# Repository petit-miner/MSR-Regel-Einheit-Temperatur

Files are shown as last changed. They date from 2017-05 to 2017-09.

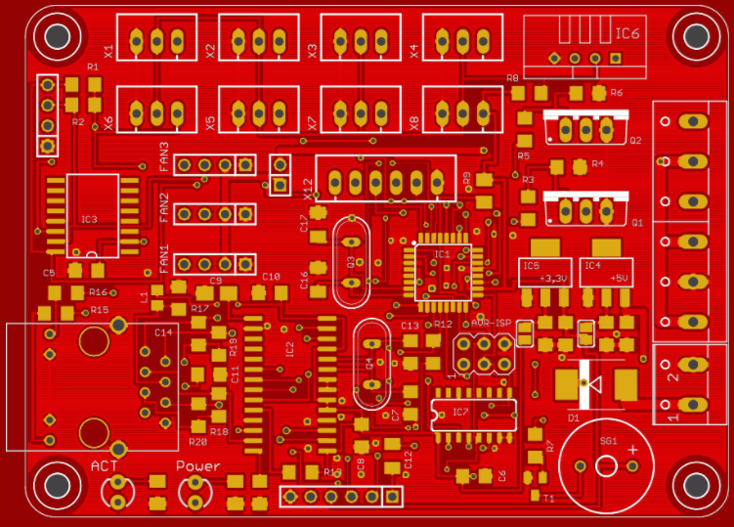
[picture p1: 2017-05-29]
Hardware/Bilder-Platine/Top.png

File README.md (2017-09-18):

# MSR-Regel-Einheit-Temperatur
Dieses Projekt entstand in der Technik / µC AG des CRBK. Die Aufgabe war es die Temperatur eines Schaltschrankes zu überwachen und ggf. mit einem Lüfter zu kühlen. <br>
Diese Platine bietet die Möglichkeit die gemessen Temperaturen auf einer micro SD Karte zu loggen und auch per Ethernet entweder als Webserver oder als Client die gemessenen Daten bereitzustellen.<br> Die RTC sorgt beim Loggen für eine ständig korrekte Zeit.<br>
Es können bis zu 8 Onewire Sensoren, 3 PC-Lüfter und 2 normale Lüfter an die Platine angeschlossen werden.
<br>
<br>
Die Gerber Dateien und der Schaltplan wurden unter der Open Source Hardware Lizenz veröffentlicht und dürfen für den nicht kommerziellen Zweck gerne weiter verwendet werden.
<br>
<br>
Dieses Projekt wurde von Marcel Thürmer, Justin Wellenberg, Julian Prochowicz und Till Flesch entwickelt.

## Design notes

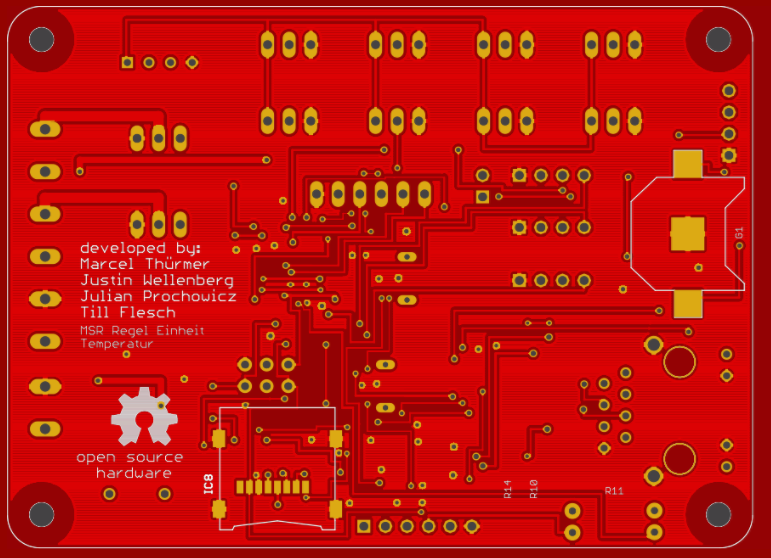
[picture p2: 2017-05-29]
Hardware/Bilder-Platine/Bottom.png

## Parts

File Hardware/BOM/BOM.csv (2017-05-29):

Part | Value | Device | Package | Description | PROD_ID | VALUE
C1 | 100nF | C-EUC1206 | C1206 | CAPACITOR, European symbol
C2 | 100nF | C-EUC1206 | C1206 | CAPACITOR, European symbol
C3 | 100nF | C-EUC1206 | C1206 | CAPACITOR, European symbol
C4 | 100nF | C-EUC1206 | C1206 | CAPACITOR, European symbol
C5 | 100nF | C-EUC1206 | C1206 | CAPACITOR, European symbol
C6 | 100nF | C-EUC1206 | C1206 | CAPACITOR, European symbol
C7 | 20pF | C-EUC1206 | C1206 | CAPACITOR, European symbol
C8 | 100nF | C-EUC1206 | C1206 | CAPACITOR, European symbol
C9 | 10µF | CPOL-EUA/3216-18W | A/3216-18W | POLARIZED CAPACITOR, European symbol
C10 | 100nF | C-EUC1206 | C1206 | CAPACITOR, European symbol
C11 | 100nF | C-EUC1206 | C1206 | CAPACITOR, European symbol
C12 | 100nF | C-EUC1206K | C1206K | CAPACITOR, European symbol
C13 | 20pF | C-EUC1206 | C1206 | CAPACITOR, European symbol
C14 | 100nF | C-EUC1206 | C1206 | CAPACITOR, European symbol
C16 | 22pF | C-EUC1206K | C1206K | CAPACITOR, European symbol
C17 | 22pF | C-EUC1206K | C1206K | CAPACITOR, European symbol
D1 | FS3J | DIODE-SMC | SMC | DIODE
D2 | LED | LED3MM | LED3MM | LEDs
D3 | LED | LED3MM | LED3MM | LEDs
G1 | RTC-battery | CR1220SMT | CR1220-SMD | CR1216/CR1220/CR1225 12mm 3V lithium coin cell
IC1 | ATMEGA328P_TQFP | ATMEGA328P_TQFP | TQFP32-08 | Popular 328P in QFP
IC2 | ENC28J60-SO | ENC28J60-SO | SO28W | Microchip 10Mbit Eth. contoller with SPI interface
IC3 | RTC | DS3231SOIC-16W | SOIC-16W
IC4 | Linearregler | LM1117 | SOT223
IC5 | Linearregler | LM1117 | SOT223 |  | IC-09069 | ATMEGA328P_TQFP
IC6 | TEMP-HUM-SENSOR-DHT22 | TEMP-HUM-SENSOR-DHT22 | TEMP-HUM-SENSOR-DHT22 | DHT22 - digital humidity & temperature sensor
IC7 | HEX_CONVERTER | HEX_CONVERTER | SO016 | 74HC4050 Hex Buffer Level Shifter SMD SO016
IC8 | TRANSFLASH-LOCK | TRANSFLASH-LOCK | TRANSFLASH-LOCK-SOCK | TransFlash TF Micro SD Card Socket Adapter
ISP1 | 10µH | L-EUL0805 | L0805 | INDUCTOR, European symbol
L1 | IRF512 | IRF512 | TO220BV | N-CHANNEL MOS FET
Q1 | IRF512 | IRF512 | TO220BV | N-CHANNEL MOS FET
Q2 | 16Mhz | XTAL/S | QS | CRYSTAL
Q3 | 25Mhz | XTAL/S | QS | CRYSTAL
Q4 | 10k | R-EU_R1206 | R1206 | RESISTOR, European symbol
R1 | 10k | R-EU_R1206 | R1206 | RESISTOR, European symbol
R2 | 270 | R-EU_R1206 | R1206 | RESISTOR, European symbol
R3 | 10k | R-EU_R1206 | R1206 | RESISTOR, European symbol
R4 | 270 | R-EU_R1206 | R1206 | RESISTOR, European symbol
R5 | 10k | R-EU_R1206 | R1206 | RESISTOR, European symbol
R6 | 1k | R-EU_R1206 | R1206 | RESISTOR, European symbol
R7 | 4,7k | R-EU_R1206 | R1206 | RESISTOR, European symbol
R8 | 10k | R-EU_M1206 | M1206 | RESISTOR, European symbol
R9 | 150 | R-EU_M1206 | M1206 | RESISTOR, European symbol
R10 | 150 | R-EU_M1206 | M1206 | RESISTOR, European symbol
R11 | 4,7K | R-EU_R1206 | R1206 | RESISTOR, European symbol
R12 | 4,7K | R-EU_R1206 | R1206 | RESISTOR, European symbol
R13 | 2.7K | R-EU_R1206 | R1206 | RESISTOR, European symbol
R14 | 1k | R-EU_R1206 | R1206 | RESISTOR, European symbol
R15 | 1k | R-EU_R1206 | R1206 | RESISTOR, European symbol
R16 | 50 | R-EU_R1206 | R1206 | RESISTOR, European symbol
R17 | 50 | R-EU_R1206 | R1206 | RESISTOR, European symbol
R18 | 50 | R-EU_R1206 | R1206 | RESISTOR, European symbol
R19 | 50 | R-EU_R1206 | R1206 | RESISTOR, European symbol
R20 | BUZZER | BUZZER | BUZZER-12MM-NS | Buzzer 12mm
SG1 | Transistor | BC817-16-NPN-SOT23-BEC | SOT23-BEC | NPN Transistror
T1 | HR911105A | HR911105A | RJ45
U$1 | JST-XH-03-PIN-LONG-PAD | JST-XH-03-PIN-LONG-PAD | JST-XH-03-PACKAGE-LONG-PAD | JST XH Connector 2 Pin
X1 | JST-XH-03-PIN-LONG-PAD | JST-XH-03-PIN-LONG-PAD | JST-XH-03-PACKAGE-LONG-PAD | JST XH Connector 2 Pin
X2 | JST-XH-03-PIN-LONG-PAD | JST-XH-03-PIN-LONG-PAD | JST-XH-03-PACKAGE-LONG-PAD | JST XH Connector 2 Pin
X3 | JST-XH-03-PIN-LONG-PAD | JST-XH-03-PIN-LONG-PAD | JST-XH-03-PACKAGE-LONG-PAD | JST XH Connector 2 Pin
X4 | JST-XH-03-PIN-LONG-PAD | JST-XH-03-PIN-LONG-PAD | JST-XH-03-PACKAGE-LONG-PAD | JST XH Connector 2 Pin
X5 | JST-XH-03-PIN-LONG-PAD | JST-XH-03-PIN-LONG-PAD | JST-XH-03-PACKAGE-LONG-PAD | JST XH Connector 2 Pin
X6 | JST-XH-03-PIN-LONG-PAD | JST-XH-03-PIN-LONG-PAD | JST-XH-03-PACKAGE-LONG-PAD | JST XH Connector 2 Pin
X7 | JST-XH-03-PIN-LONG-PAD | JST-XH-03-PIN-LONG-PAD | JST-XH-03-PACKAGE-LONG-PAD | JST XH Connector 2 Pin
X8 | Wago Schraubklemme | W237-102 | W237-102 | WAGO SCREW CLAMP
X9 | Wago Schraubklemme | W237-6 | W237-6 | WAGO SCREW CLAMP
X10 | JST-XH-06-PIN-LONG-PAD | JST-XH-06-PIN-LONG-PAD | JST-XH-06-PACKAGE-LONG-PAD | JST XH Connector 2 Pin
X12

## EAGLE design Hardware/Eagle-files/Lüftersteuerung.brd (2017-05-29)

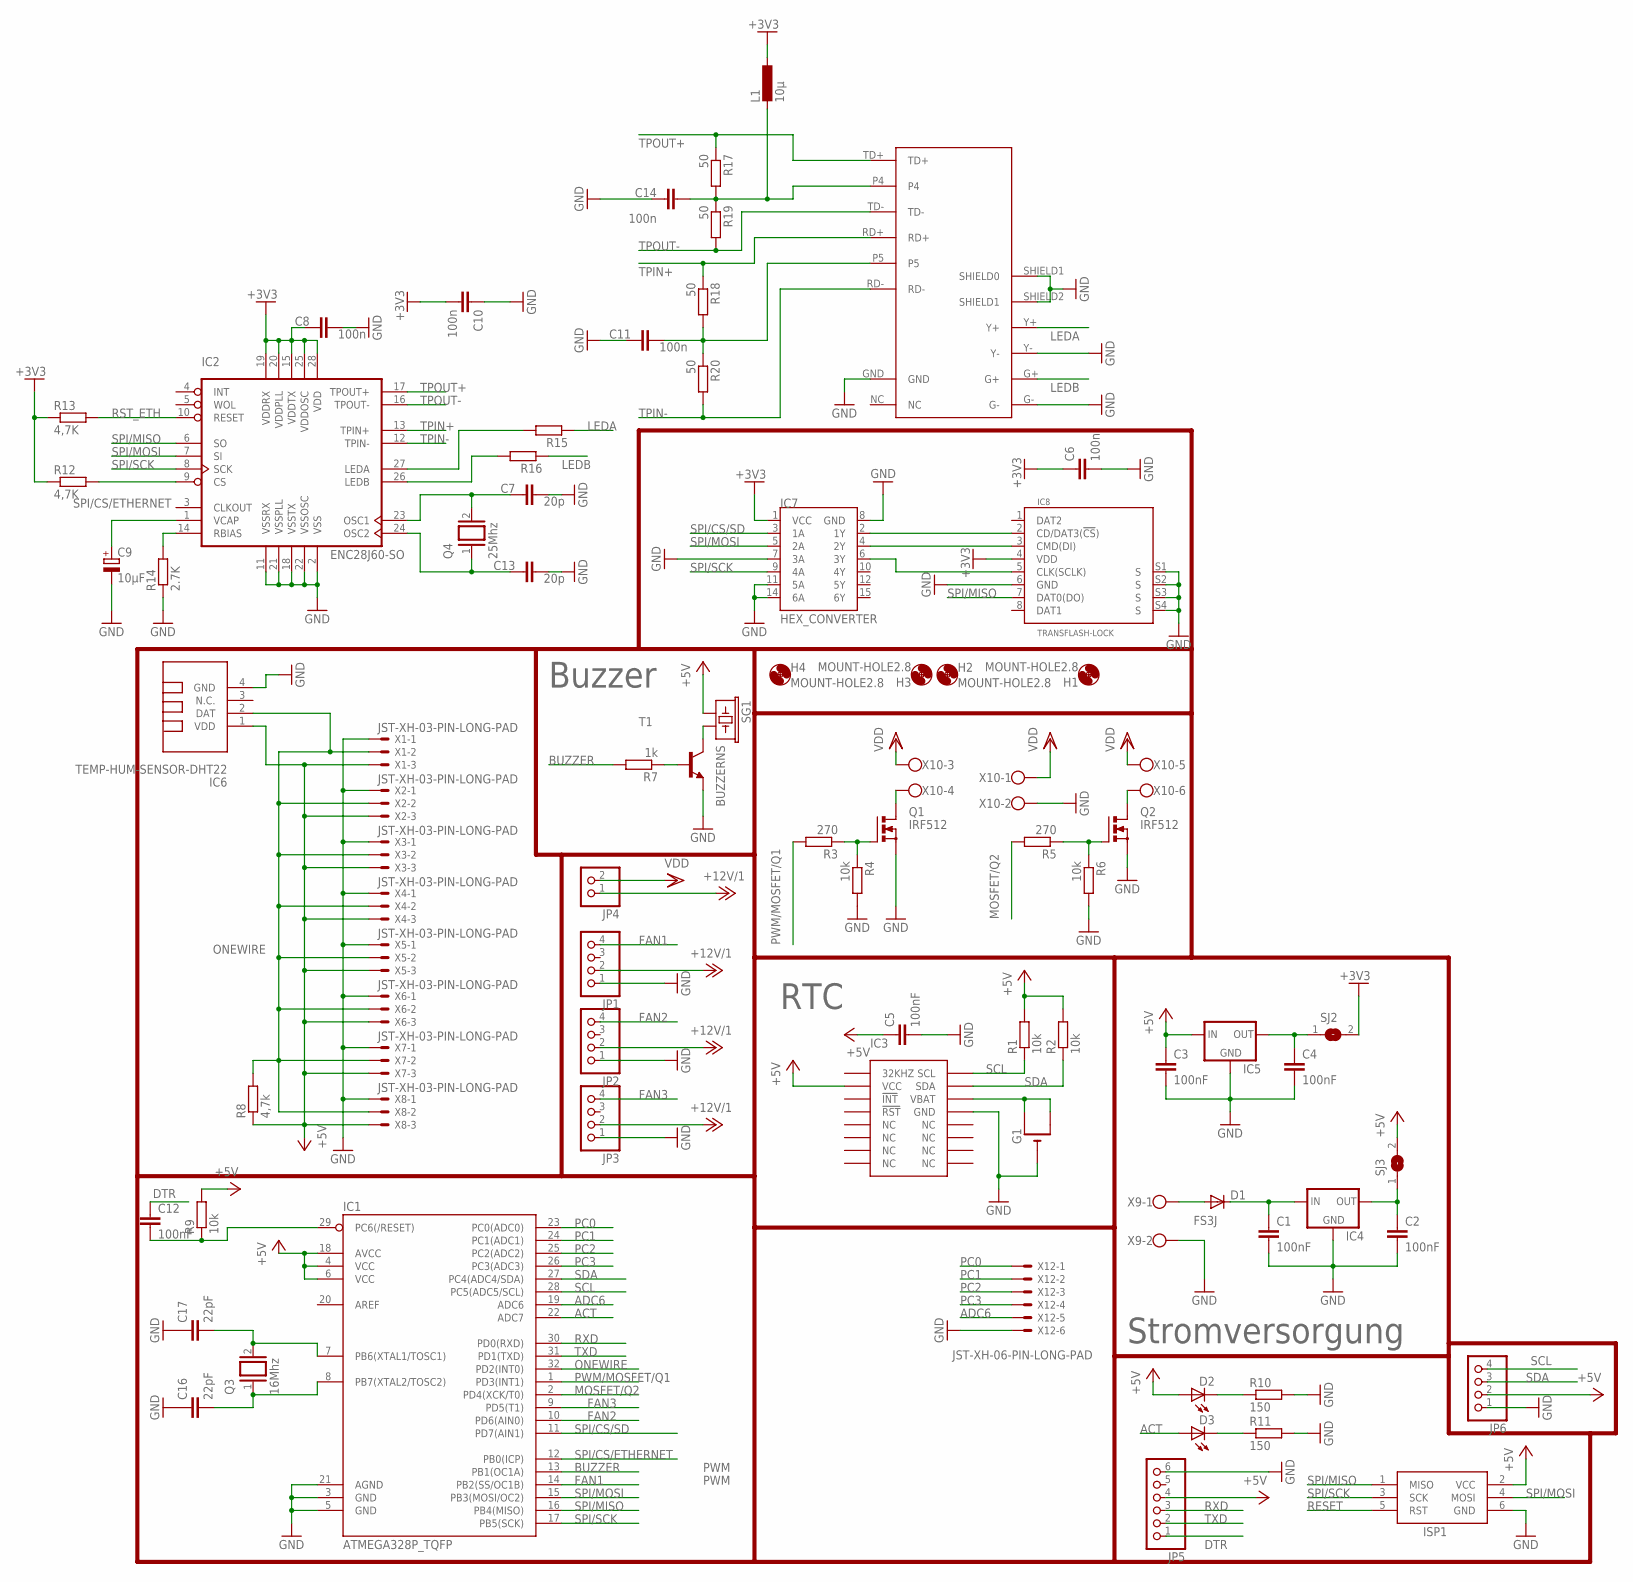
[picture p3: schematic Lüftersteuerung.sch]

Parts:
C1, C2, C3, C4, C5: 100nF; C1206
C6, C8, C10, C11, C14: 100n; C1206
C7, C13: 20p; C1206
C9: 10µF; A/3216-18W
C12: 100nF; C1206K
C16, C17: 22pF; C1206K
D1: FS3J; SMC
D2, D3: LED3MM
G1: CR1220SMT; CR1220-SMD
H1, H2, H3, H4: MOUNT-HOLE2.8; 2,8
IC1: ATMEGA328P_TQFP; TQFP32-08
IC2: ENC28J60-SO; SO28W
IC3: DS3231SOIC-16W; SOIC-16W
IC4, IC5: LM1117; SOT223
IC6: TEMP-HUM-SENSOR-DHT22
IC7: HEX_CONVERTER; SO016
IC8: TRANSFLASH-LOCK; TRANSFLASH-LOCK-SOCK
ISP1: AVRISP-6; AVRISP
JP1, JP2, JP3, JP6: PINHD-1X4; 1X04
JP4: PINHD-1X2; 1X02
JP5: PINHD-1X6; 1X06
L1: 10µ; L0805
Q1, Q2: IRF512; TO220BV
Q3: 16Mhz; QS
Q4: 25Mhz; QS
R1, R2, R4, R6: 10k; R1206
R3, R5: 270; R1206
R7: 1k; R1206
R8: 4,7k; R1206
R9: 10k; M1206
R10, R11: 150; M1206
R12, R13: 4,7K; R1206
R14: 2.7K; R1206
R15, R16: R-EU_R1206; R1206
R17, R18, R19, R20: 50; R1206
SG1: BUZZERNS; BUZZER-12MM-NS
SJ2, SJ3: SJ
T1: BC817-16-NPN-SOT23-BEC; SOT23-BEC
U$1: HR911105A; RJ45
X1, X2, X3, X4, X5, X6, X7, X8: JST-XH-03-PIN-LONG-PAD; JST-XH-03-PACKAGE-LONG-PAD
X9: W237-102
X10: W237-6
X12: JST-XH-06-PIN-LONG-PAD; JST-XH-06-PACKAGE-LONG-PAD

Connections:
+3V3: C6.1, C8.1, C10.2, IC2.15 (VDDTX), IC2.19 (VDDRX), IC2.20 (VDDPLL), IC2.25 (VDDOSC), IC2.28 (VDD), IC7.1 (VCC), IC8.4 (VDD), L1.1, R12.1, R13.1, SJ2.2
+5V: C3.1, C5.1, D2.A, IC1.4 (VCC), IC1.6 (VCC), IC1.18 (AVCC), IC3.2 (VCC), IC5.3 (IN), IC6.1 (VDD), ISP1.2 (VCC), JP5.4, JP6.2, R1.2, R2.2, R8.1, R9.2, SG1.+ (1), SJ3.2, X1.3, X2.3, X3.3, X4.3, X5.3, X6.3, X7.3, X8.3
+12V/1: JP1.2, JP2.2, JP3.2, JP4.1
ACT: D3.A, IC1.22 (ADC7)
ADC6: IC1.19 (ADC6), X12.5
BUZZER: IC1.13 (PB1(OC1A)), R7.2
DTR: C12.1, JP5.1
FAN1: IC1.14 (PB2(SS/OC1B)), JP1.4
FAN2: IC1.10 (PD6(AIN0)), JP2.4
FAN3: IC1.9 (PD5(T1)), JP3.4
GND: C1.2, C2.2, C3.2, C4.2, C5.2, C6.2, C7.2, C8.2, C9.-, C10.1, C11.1, C13.1, C14.1, C16.1, C17.1, G1.-, IC1.3 (GND), IC1.5 (GND), IC1.21 (AGND), IC2.2 (VSS), IC2.11 (VSSRX), IC2.18 (VSSTX), IC2.21 (VSSPLL), IC2.22 (VSSOSC), IC3.13 (GND), IC4.1 (GND), IC5.1 (GND), IC6.4 (GND), IC7.7 (3A), IC7.8 (GND), IC7.11 (5A), IC7.14 (6A), IC8.6 (GND), IC8.S1 (S), IC8.S2 (S), IC8.S3 (S), IC8.S4 (S), ISP1.6 (GND), JP1.1, JP2.1, JP3.1, JP5.6, JP6.1, Q1.S, Q2.S, R4.2, R6.2, R10.2, R11.2, R14.1, T1.E, U$1.G-, U$1.GND, U$1.SHIELD1 (SHIELD0), U$1.SHIELD2 (SHIELD1), U$1.Y-, X1.1, X2.1, X3.1, X4.1, X5.1, X6.1, X7.1, X8.1, X9.2, X10.2, X12.6
LEDA: R15.1, U$1.Y+
LEDB: R16.1, U$1.G+
MOSFET/Q2: IC1.2 (PD4(XCK/T0)), R5.2
unnamed: D1.A, X9.1
unnamed: C1.1, D1.C, IC4.3 (IN)
unnamed: C2.1, IC4.2 (OUT), SJ3.1
unnamed: G1.+$1 (+), G1.+$2 (+1), IC3.14 (VBAT)
unnamed: Q1.D, X10.4
unnamed: Q1.G, R3.1, R4.1
unnamed: Q2.D, X10.6
unnamed: SG1.- (2), T1.C
unnamed: Q2.G, R5.1, R6.1
unnamed: R7.1, T1.B
unnamed: C16.2, IC1.8 (PB7(XTAL2/TOSC2)), Q3.1
unnamed: C17.2, IC1.7 (PB6(XTAL1/TOSC1)), Q3.2
unnamed: D2.K (C), R10.1
unnamed: D3.K (C), R11.1
unnamed: IC7.2 (1Y), IC8.2 (CD/DAT3(!CS!))
unnamed: IC7.4 (2Y), IC8.3 (CMD(DI))
unnamed: IC7.6 (3Y), IC8.5 (CLK(SCLK))
unnamed: C13.2, IC2.24 (OSC2), Q4.1
unnamed: IC2.14 (RBIAS), R14.2
unnamed: C7.1, IC2.23 (OSC1), Q4.2
unnamed: C9.+, IC2.1 (VCAP)
unnamed: C14.2, L1.2, R17.2, R19.1, U$1.P4
unnamed: IC2.26 (LEDB), R16.2
unnamed: IC2.27 (LEDA), R15.2
unnamed: C11.2, R18.2, R20.1, U$1.P5
unnamed: C4.1, IC5.2 (OUT), SJ2.1
ONEWIRE: IC1.32 (PD2(INT0)), IC6.2 (DAT), R8.2, X1.2, X2.2, X3.2, X4.2, X5.2, X6.2, X7.2, X8.2
PC0: IC1.23 (PC0(ADC0)), X12.1
PC1: IC1.24 (PC1(ADC1)), X12.2
PC2: IC1.25 (PC2(ADC2)), X12.3
PC3: IC1.26 (PC3(ADC3)), X12.4
PWM/MOSFET/Q1: IC1.1 (PD3(INT1)), R3.2
RESET: C12.2, IC1.29 (PC6(/RESET)), ISP1.5 (RST), R9.1
RST_ETH: IC2.10 (RESET), R13.2
RXD: IC1.30 (PD0(RXD)), JP5.3
SCL: IC1.28 (PC5(ADC5/SCL)), IC3.16 (SCL), JP6.4, R1.1
SDA: IC1.27 (PC4(ADC4/SDA)), IC3.15 (SDA), JP6.3, R2.1
SPI/CS/ETHERNET: IC1.12 (PB0(ICP)), IC2.9 (CS), R12.2
SPI/CS/SD: IC1.11 (PD7(AIN1)), IC7.3 (1A)
SPI/MISO: IC1.16 (PB4(MISO)), IC2.6 (SO), IC8.7 (DAT0(DO)), ISP1.1 (MISO)
SPI/MOSI: IC1.15 (PB3(MOSI/OC2)), IC2.7 (SI), IC7.5 (2A), ISP1.4 (MOSI)
SPI/SCK: IC1.17 (PB5(SCK)), IC2.8 (SCK), IC7.9 (4A), ISP1.3 (SCK)
TPIN+: IC2.13 (TPIN+), R18.1, U$1.RD+
TPIN-: IC2.12 (TPIN-), R20.2, U$1.RD-
TPOUT+: IC2.17 (TPOUT+), R17.1, U$1.TD+
TPOUT-: IC2.16 (TPOUT-), R19.2, U$1.TD-
TXD: IC1.31 (PD1(TXD)), JP5.2
VDD: JP4.2, X10.1, X10.3, X10.5

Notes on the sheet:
Stromversorgung
PWM
RTC
Buzzer

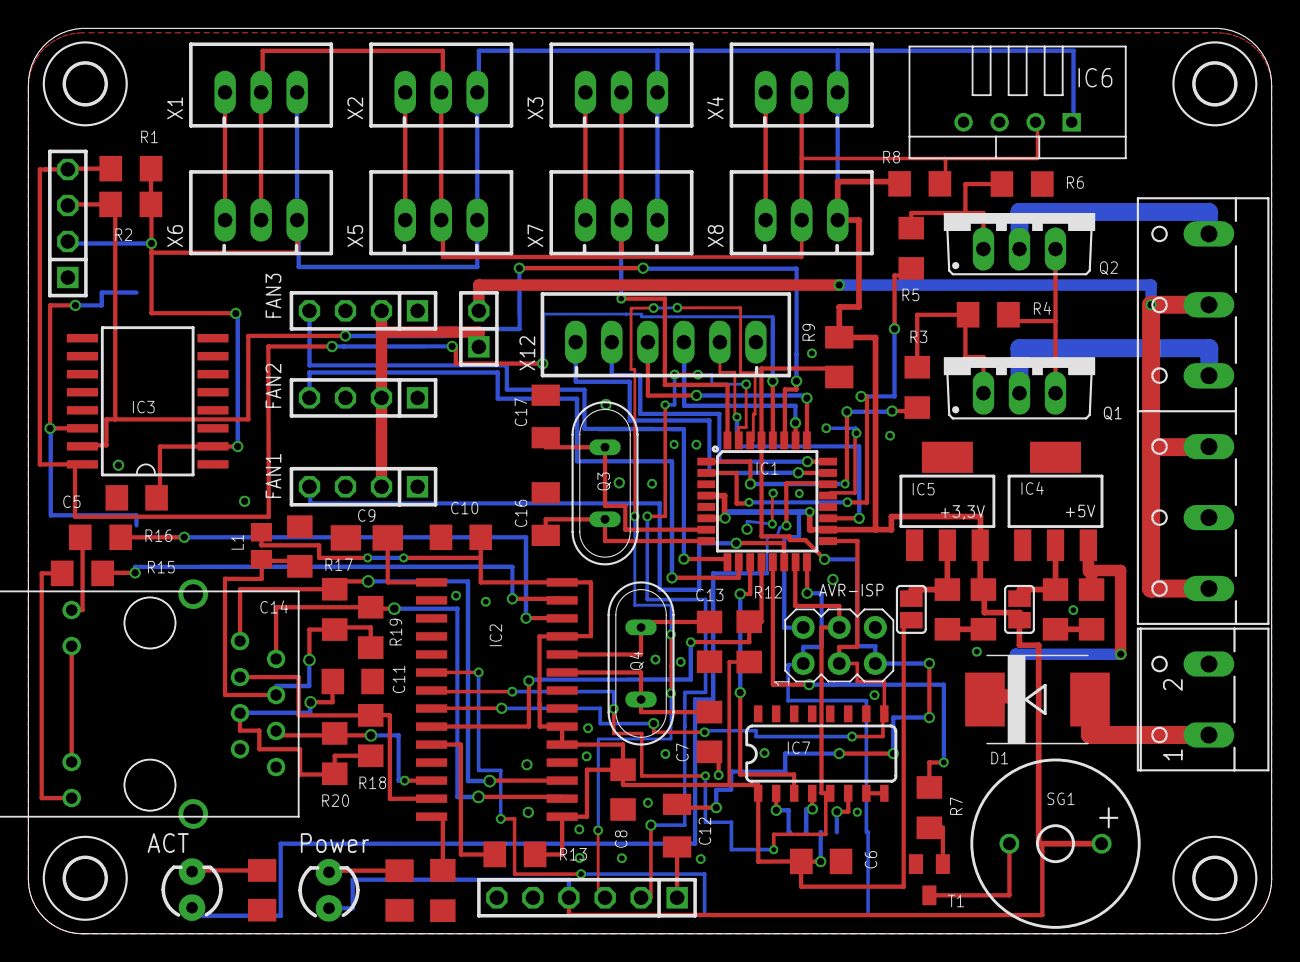
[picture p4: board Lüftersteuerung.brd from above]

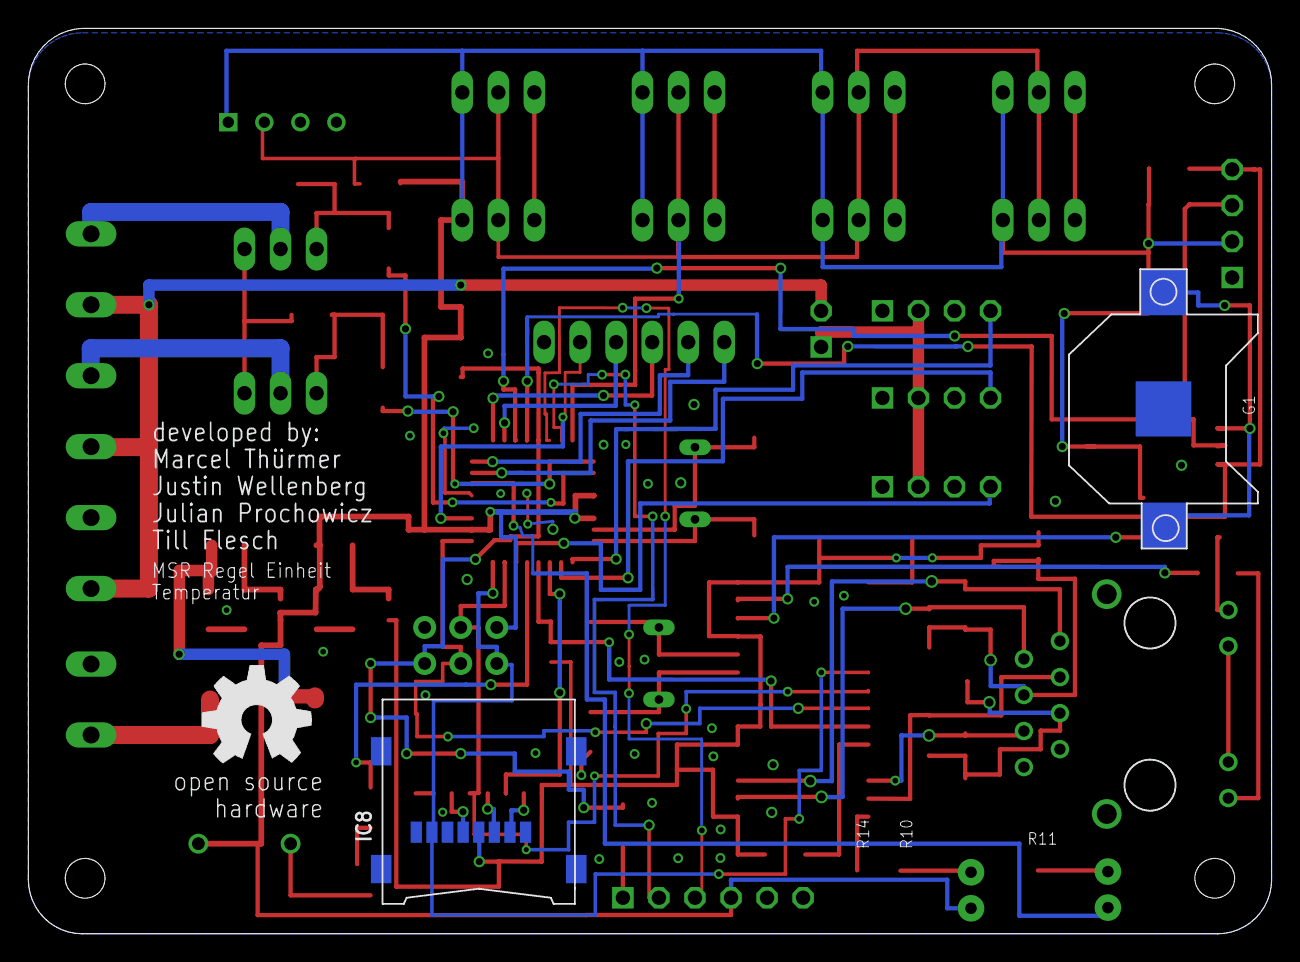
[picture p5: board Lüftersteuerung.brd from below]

Board: 2 copper layers, 87.6 x 63.8 mm, 81 parts (3 on the bottom side), 62 nets.

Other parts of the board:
U$2: OSHW_8MM

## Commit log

2017-05-29 Added folder Hardware
    [BOM.csv, Lüftersteuerung.brd, Lüftersteuerung.sch]
2017-05-29 Added photos of the pcb

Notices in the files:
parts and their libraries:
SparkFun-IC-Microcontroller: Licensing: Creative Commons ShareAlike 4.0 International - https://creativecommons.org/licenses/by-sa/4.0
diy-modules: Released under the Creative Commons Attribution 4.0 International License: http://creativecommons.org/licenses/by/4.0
